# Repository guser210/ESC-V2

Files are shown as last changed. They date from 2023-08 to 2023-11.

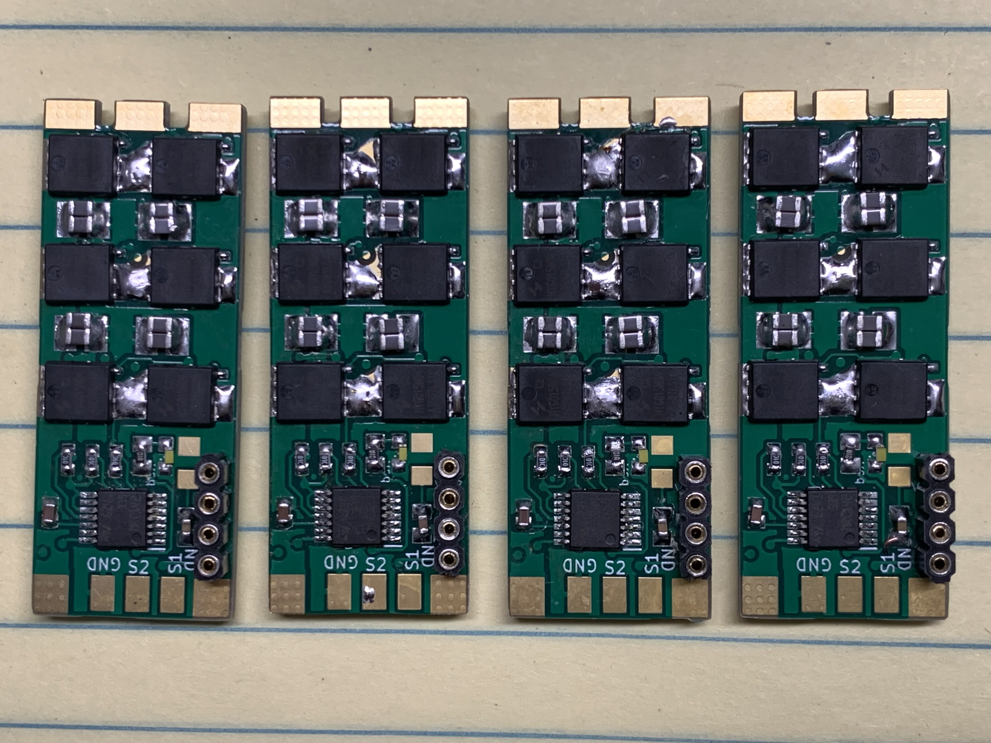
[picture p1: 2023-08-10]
images/ESC back.jpg

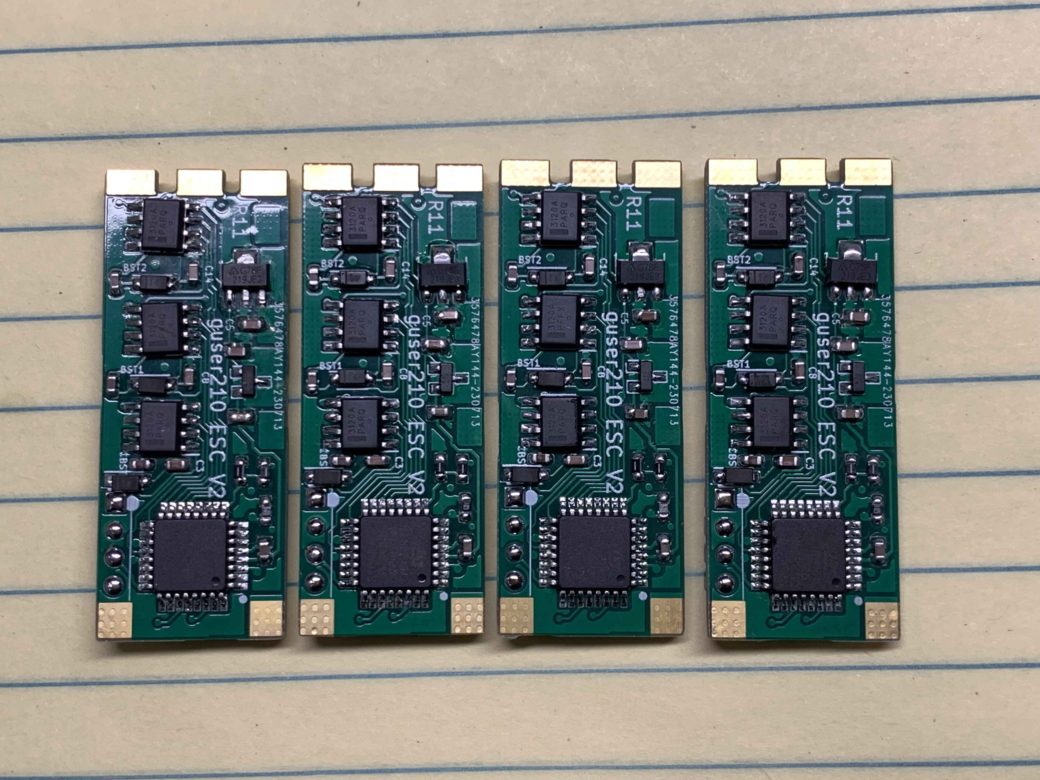
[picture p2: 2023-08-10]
images/ESC Front.jpg

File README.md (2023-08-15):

# ESC-V2
Full STM32CubeEDI project of the ESC I currently use on my Drones.

You can find more information on the link below,

https://discord.gg/pByahDupYP





ESC Front
ESC back






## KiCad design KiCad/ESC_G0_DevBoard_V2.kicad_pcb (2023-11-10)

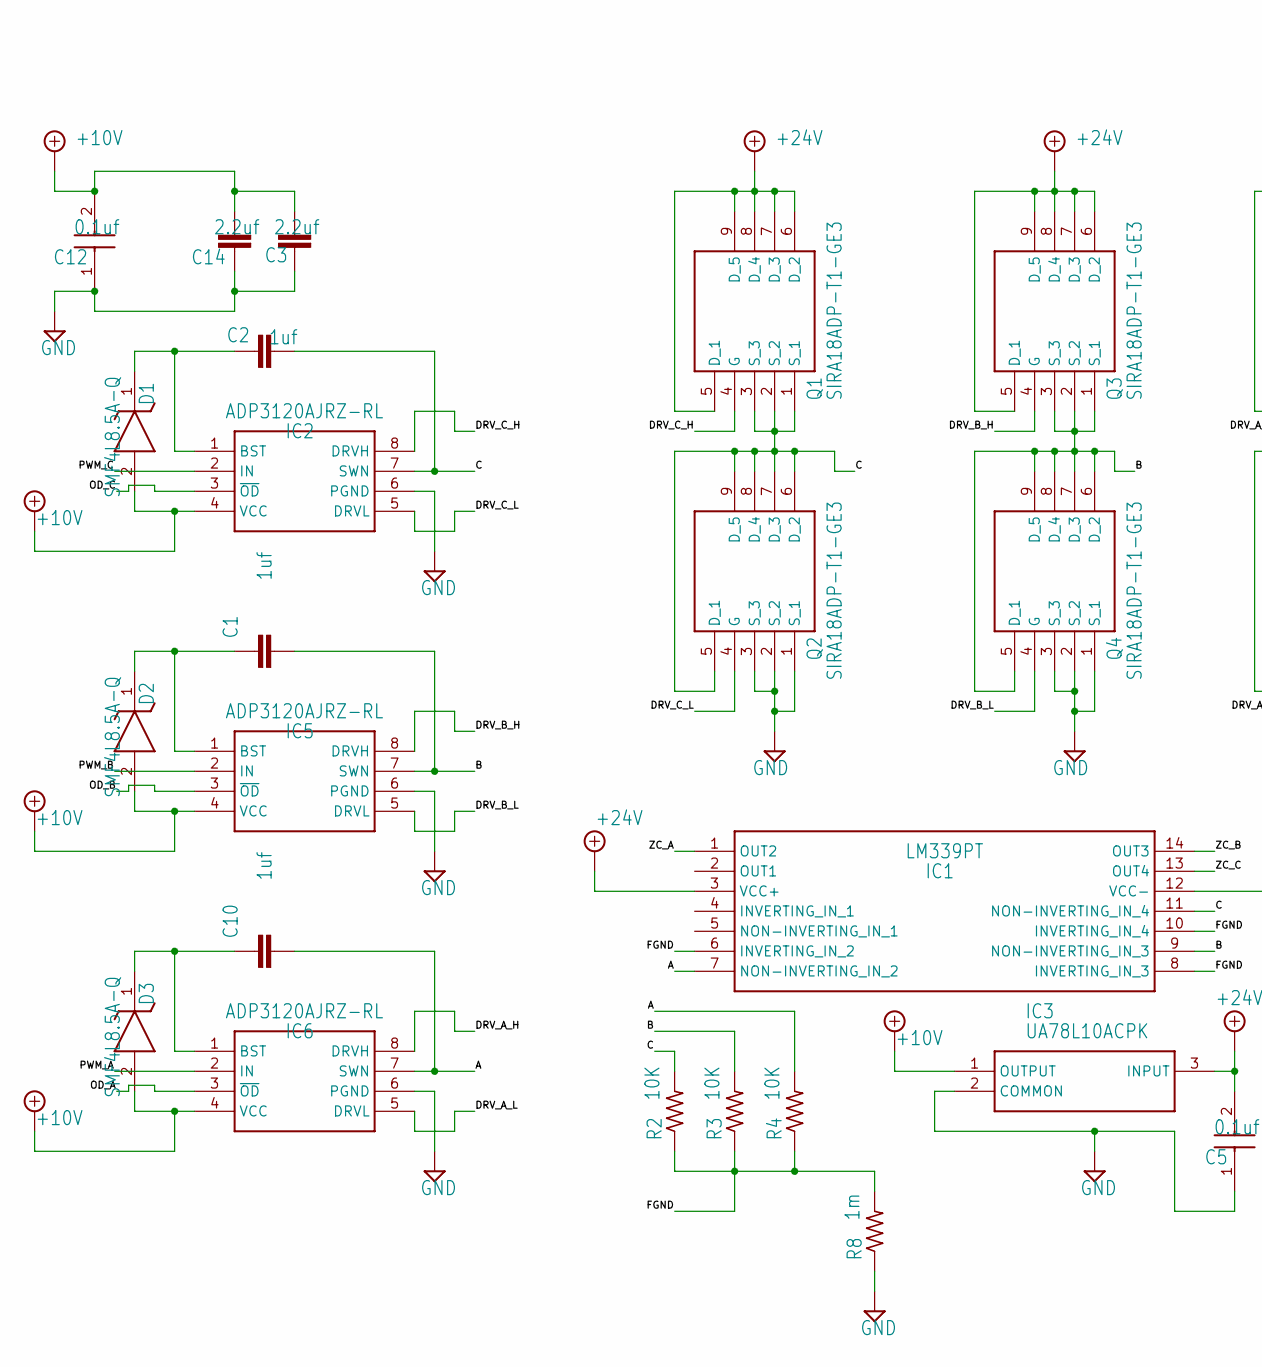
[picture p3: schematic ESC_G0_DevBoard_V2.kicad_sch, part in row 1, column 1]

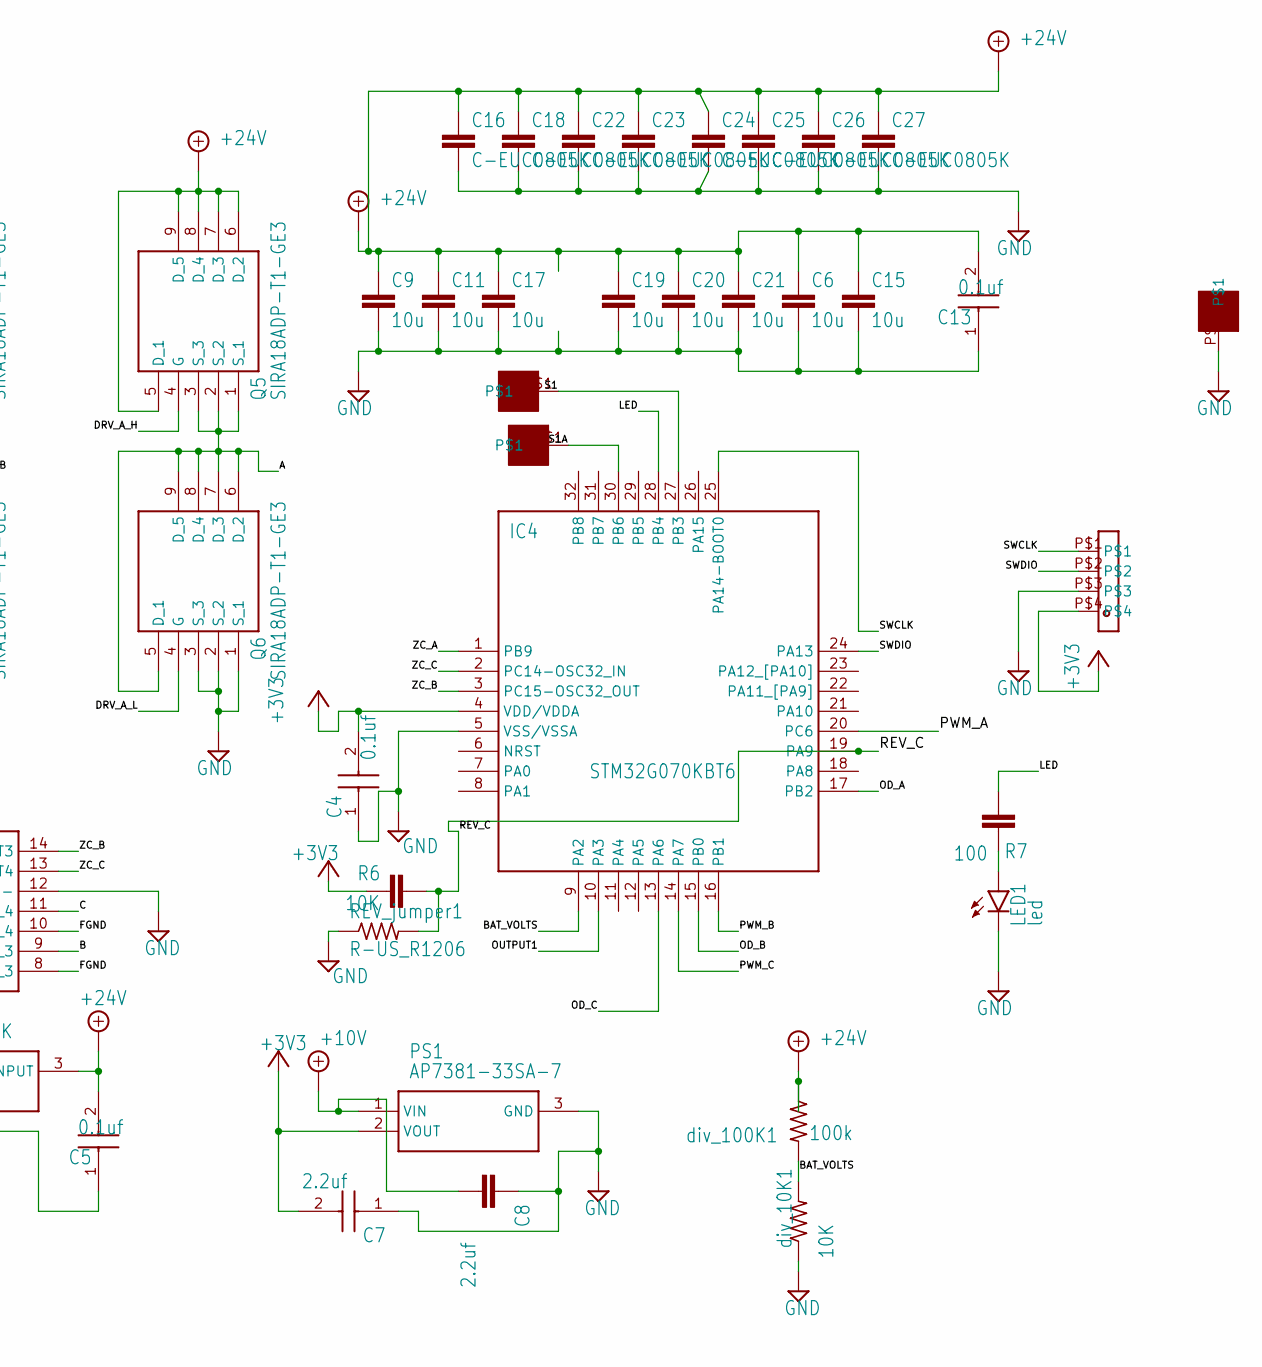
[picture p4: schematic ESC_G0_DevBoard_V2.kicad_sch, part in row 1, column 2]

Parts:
C1, C2, C10: 1uf; C0805K
C3, C8, C14: 2.2uf; C0805K
C4, C5, C12, C13: 0.1uf; CAPC2012X135N
C6, C9, C11, C15, C17, C19, C20, C21: 10u; C1206K
C7: 2.2uf; CAPC2012X135N
C16, C18, C22, C23, C24, C25, C26, C27: C-EUC0805K; C0805K
D1, D2, D3: SMF4L8.5A-Q; SODFL3716X135N
IC1: LM339PT; SOP65P640X120-14N
IC2, IC5, IC6: ADP3120AJRZ-RL; SOIC127P600X175-8N
IC3: UA78L10ACPK; PK(R-PSSO-F3)
IC4: STM32G070KBT6; QFP80P900X900X160-32N
LED1: led; SML0805
PS1: AP7381-33SA-7; SOT96P240X120-3N
Q1, Q2, Q3, Q4, Q5, Q6: SIRA18ADP-T1-GE3; SIRA18ADPT1GE3
R2, R3, R4: 10K; R0603
R6: 10K; C0805K
R7: 100; C0805K
R8: 1m; R0603
REV_jumper1: R-US_R1206; R1206
U$1, U$2, U$3: 3X3_PAD
U$4: STLINK_HEADER
div_10K1: 10K; R0603
div_100K1: 100k; R0603

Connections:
+3V3: C4.2, C7.2, IC4.4 (VDD/VDDA), PS1.2 (VOUT), R6.2, U$4.P$4
+10V: C3.2, C8.2, C12.2, C14.2, D1.2 (A), D2.2 (A), D3.2 (A), IC2.4 (VCC), IC3.1 (OUTPUT), IC5.4 (VCC), IC6.4 (VCC), PS1.1 (VIN)
+24V: C5.2, C6.1, C9.1, C11.1, C13.2, C15.1, C16.1, C17.1, C18.1, C19.1, C20.1, C21.1, C22.1, C23.1, C24.1, C25.1, C26.1, C27.1, IC1.3 (VCC+), IC3.3 (INPUT), Q1.5 (D_1), Q1.6 (D_2), Q1.7 (D_3), Q1.8 (D_4), Q1.9 (D_5), Q3.5 (D_1), Q3.6 (D_2), Q3.7 (D_3), Q3.8 (D_4), Q3.9 (D_5), Q5.5 (D_1), Q5.6 (D_2), Q5.7 (D_3), Q5.8 (D_4), Q5.9 (D_5), div_100K1.1
/A: C10.2, IC1.7 (NON-INVERTING_IN_2), IC6.7 (SWN), Q5.1 (S_1), Q5.2 (S_2), Q5.3 (S_3), Q6.5 (D_1), Q6.6 (D_2), Q6.7 (D_3), Q6.8 (D_4), Q6.9 (D_5), R4.2; also elsewhere on the board
/B: C1.2, IC1.9 (NON-INVERTING_IN_3), IC5.7 (SWN), Q3.1 (S_1), Q3.2 (S_2), Q3.3 (S_3), Q4.5 (D_1), Q4.6 (D_2), Q4.7 (D_3), Q4.8 (D_4), Q4.9 (D_5), R3.2; also elsewhere on the board
/BAT_VOLTS: IC4.9 (PA2), div_10K1.2, div_100K1.2
/C: C2.2, IC1.11 (NON-INVERTING_IN_4), IC2.7 (SWN), Q1.1 (S_1), Q1.2 (S_2), Q1.3 (S_3), Q2.5 (D_1), Q2.6 (D_2), Q2.7 (D_3), Q2.8 (D_4), Q2.9 (D_5), R2.2; also elsewhere on the board
/DRV_A_H: IC6.8 (DRVH), Q5.4 (G)
/DRV_A_L: IC6.5 (DRVL), Q6.4 (G)
/DRV_B_H: IC5.8 (DRVH), Q3.4 (G)
/DRV_B_L: IC5.5 (DRVL), Q4.4 (G)
/DRV_C_H: IC2.8 (DRVH), Q1.4 (G)
/DRV_C_L: IC2.5 (DRVL), Q2.4 (G)
/FGND: IC1.6 (INVERTING_IN_2), IC1.8 (INVERTING_IN_3), IC1.10 (INVERTING_IN_4), R2.1, R3.1, R4.1, R8.2
/LED: IC4.28 (PB4), R7.2
/OD_A: IC4.17 (PB2), IC6.3 (~OD)
/OD_B: IC4.15 (PB0), IC5.3 (~OD)
/OD_C: IC2.3 (~OD), IC4.13 (PA6)
/OUTPUT1: IC4.10 (PA3)
/PWM_A: IC4.20 (PC6), IC6.2 (IN)
/PWM_B: IC4.16 (PB1), IC5.2 (IN)
/PWM_C: IC2.2 (IN), IC4.14 (PA7)
/REV_C: IC4.19 (PA9), R6.1, REV_jumper1.2
/S1: IC4.27 (PB3), U$1.P$1
/S1A: IC4.30 (PB6), U$2.P$1
/SWCLK: IC4.25 (PA14-BOOT0), U$4.P$1
/SWDIO: IC4.24 (PA13), U$4.P$2
/ZC_A: IC1.1 (OUT2), IC4.1 (PB9)
/ZC_B: IC1.14 (OUT3), IC4.3 (PC15-OSC32_OUT)
/ZC_C: IC1.13 (OUT4), IC4.2 (PC14-OSC32_IN)
GND: C3.1, C4.1, C5.1, C6.2, C7.1, C8.1, C9.2, C11.2, C12.1, C13.1, C14.1, C15.2, C16.2, C17.2, C18.2, C19.2, C20.2, C21.2, C22.2, C23.2, C24.2, C25.2, C26.2, C27.2, IC1.12 (VCC-), IC2.6 (PGND), IC3.2 (COMMON), IC3.4, IC4.5 (VSS/VSSA), IC5.6 (PGND), IC6.6 (PGND), LED1.C, PS1.3 (GND), Q2.1 (S_1), Q2.2 (S_2), Q2.3 (S_3), Q4.1 (S_1), Q4.2 (S_2), Q4.3 (S_3), Q6.1 (S_1), Q6.2 (S_2), Q6.3 (S_3), R8.1, REV_jumper1.1, U$3.P$1, U$4.P$3, div_10K1.1
unnamed 31: C1.1, D2.1 (K), IC5.1 (BST); also elsewhere on the board
unnamed 32: C2.1, D1.1 (K), IC2.1 (BST); also elsewhere on the board
unnamed 33: C10.1, D3.1 (K), IC6.1 (BST); also elsewhere on the board
unnamed: LED1.A, R7.1

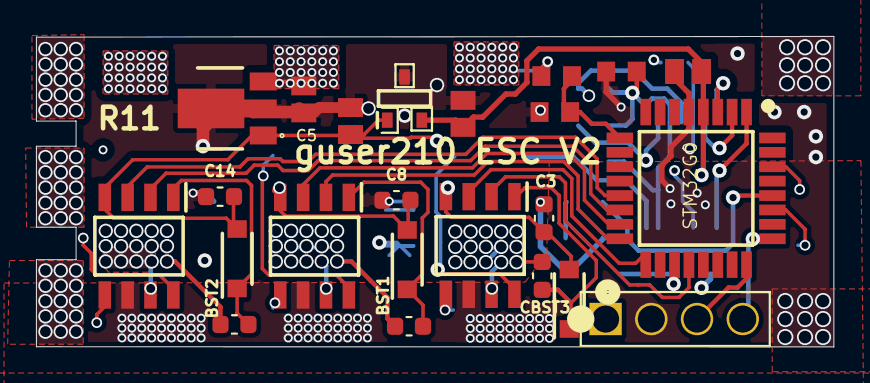
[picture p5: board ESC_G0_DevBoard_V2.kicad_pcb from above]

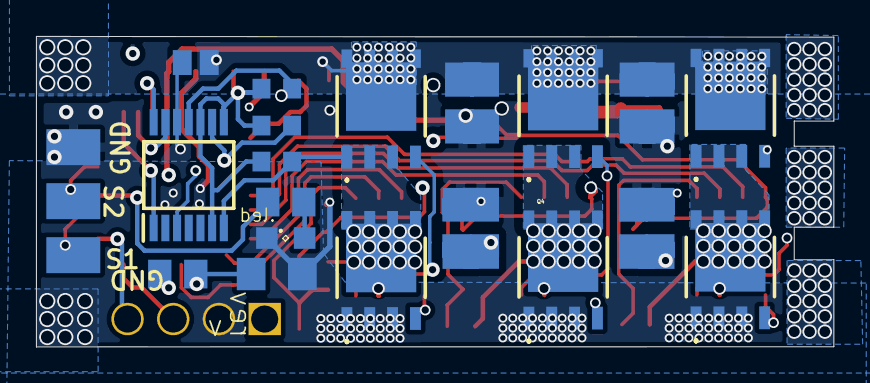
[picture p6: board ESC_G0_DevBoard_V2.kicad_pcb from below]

Board: 8 copper layers, 44.3 x 17.2 mm, 57 parts (34 on the bottom side), 34 nets.

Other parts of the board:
BST1, BST2: 1uf; C_0603_1608Metric
CBST3: 1uf; C_0603_1608Metric

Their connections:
/A: CBST3.2; also elsewhere on the board
/B: BST1.2; also elsewhere on the board
/C: BST2.2; also elsewhere on the board
unnamed 31: BST1.1; also elsewhere on the board
unnamed 32: BST2.1; also elsewhere on the board
unnamed 33: CBST3.1; also elsewhere on the board

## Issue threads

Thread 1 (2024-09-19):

Can do install am32 firmware?

adamalbarr, 2024-09-19:

aviontics, 2025-01-28:
What firmware does it support?

guser210, 2025-02-23:
This is demo project with less than ideal fet drivers, I do not believe there is firmware compatible with it.

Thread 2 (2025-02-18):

Inquiry About Using ESC V2 for Custom PCB

dstromeng, 2025-02-18:
First off, great work on this project! I’ve been going through your ESC V2 design and firmware, and I’d like to use it as the foundation for a custom PCB for my application. I have a few questions regarding your implementation:

1. Have you designed your own MCU breakout board for this project, or are you using an off-the-shelf development board?

2. Can this ESC be controlled using a standard PWM signal or an RC servo signal, or would it require modifications?

I appreciate any guidance you can provide, and I’d love to share updates on my custom implementation as I progress.

Thanks.

guser210, 2025-02-23:
Q: Have you designed your own MCU breakout board for this project, or are you using an off-the-shelf development board?
A: I have a newer sinlge ESC board design compatible with other firmware.

Q: Can this ESC be controlled using a standard PWM signal or an RC servo signal, or would it require modifications?
A: not in this current firmware however, I have new firmware coming out soon for the AT32F4 MCU, Current firmware of Gil32 is closed for now.
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

dstromeng, 2025-02-23:
Hi @guser210
Thanks for getting back.

I have made the custom PCB based on ESC v2 and will be testing it once it arrives sometimes next week.
I am not a PCB designer by far but hopefully it should work.

It would be really interesting to build and test your ESC V3 with Firmware V3.
Let me know if that's possible.

Regards.

guser210, 2025-02-23:
I can give you the design files on my discord, I will be available later tonight (USA time).

https://discord.gg/pByahDupYP

dstromeng, 2025-02-23:
Hi @guser210
I says the discord link is expired

guser210, 2025-02-23:
https://discord.gg/QbzVhgNJhk

dstromeng, 2025-02-23:
Hi @guser210
That works.
Thanks

dstromeng, 2025-02-24:
Hi @guser210
Can the V3 firmware work with v2 ESSc?

Regards.

dstromeng, 2025-02-25:
Hi @guser210
Funny enough I haven't used discord that much before.
Have you already shared V3 firmware and designs.

I did join your server using the link but couldn't find anything.

Regards.

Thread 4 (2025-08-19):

Support Needed for ESC V2

aiswaryaaishh, 2025-08-19:
Dear Sir,

I have assembled and tested the ESC V2 design from your GitHub repository, but it is not working as expected. The MOSFET driver is not switching properly. Could you please suggest a solution to fix this issue?

I am glad to be in touch with you. Thank you.

guser210, 2025-08-24:
Sorry, this project was done as a demo and I am not supporting it, I do have a supported project called Gil32_Firmware and bootloader.

aiswaryaaishh, 2025-08-30:
If the Gill32_Firmware includes any hardware design, could you please share it?

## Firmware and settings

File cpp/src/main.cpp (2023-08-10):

/*
 * main.cpp
 * ESC_V1.4_TEST_Variable
 *  Created on: July 18, 2022
 *      Author: gvargas
 */

#include "main.h"

extern "C" {
extern TIM_HandleTypeDef htim1;		// Signal input capture.
extern TIM_HandleTypeDef htim3;		// PWM driver.
extern TIM_HandleTypeDef htim7;		// Generic timer.

extern TIM_HandleTypeDef htim6;		// RPM.
extern TIM_HandleTypeDef htim14;		// RPM.
extern TIM_HandleTypeDef htim15;		// Low Bat warning.

extern TIM_HandleTypeDef htim16;	// commutator delay.
extern TIM_HandleTypeDef htim17;	// commutator bump timer.
extern ADC_HandleTypeDef hadc1;	// battery voltages.
extern DMA_HandleTypeDef hdma_memtomem_dma1_channel6;
extern DMA_HandleTypeDef hdma_tim1_ch3;


extern volatile uint8_t initComplete;

}

volatile uint8_t disableBump;

volatile uint32_t eRPM = 0;
volatile uint32_t RPM = 0;
volatile uint32_t RPMOld = 0;
volatile uint32_t maxRPM = 0;

volatile uint8_t newDmaSignal = 0;
volatile uint16_t dmaSignal[32] = { 0 };
volatile uint16_t dmaSignalESC[32] = { 0 };
volatile uint16_t dmaSignalMem2Mem[32] = { 0 };
volatile int16_t dmaSignalDiff[33] = { 0 };
volatile uint16_t dmaSignalNormalized[32] = { 0 };
volatile uint16_t dmaESCSignal[33] = { 0 };
volatile uint16_t motorSpeed = 0;
volatile uint16_t motorSpeedCurrent = 0;
volatile uint16_t motorSpeedCurrentOld = 0;
//void beepNoSPin(uint16_t ms ,uint16_t ps );
void beepNoSPin(uint16_t ms = 40, uint16_t ps = 24);
inline uint16_t map(int x, int in_min, int in_max, int out_min, int out_max);
//////////////////////////////////////////////////////////////////////
const uint16_t dmaPulse = 1;
const uint16_t dmaPulseReload = 1024;	//2048;//1024;//512;
//const uint16_t dmaPulse = 2;
//const uint16_t dmaPulseReload = 512;
volatile uint16_t dmaBuffer[dmaPulse] = { 0 };
volatile uint16_t dmaBufferA[dmaPulse] = { 0 };
volatile uint16_t dmaBufferB[dmaPulse] = { 0 };
volatile uint16_t dmaBufferC[dmaPulse] = { 0 };
volatile uint16_t resolution = dmaPulse * dmaPulseReload;

inline void startMotors();
inline void stopMotors();

const uint32_t zcOff[6] = {	//
		ZC_B_Pin, // B
		ZC_A_Pin, // A
		ZC_C_Pin, // C
		ZC_B_Pin, // B
		ZC_A_Pin, // A
		ZC_C_Pin, // C
	};

const uint32_t odLow[6] = { //
		OD_C_Pin, // C
		OD_C_Pin, // C
		OD_A_Pin, // A
		OD_A_Pin, // A
		OD_B_Pin, // B
		OD_B_Pin, // B
	};
const uint32_t odHigh[6] = { //
		OD_A_Pin, // A
		OD_B_Pin, // B
		OD_B_Pin, // B
		OD_C_Pin, // C
		OD_C_Pin, // C
		OD_A_Pin, // A
	};

const uint32_t odOff[6] = { //
		OD_B_Pin, // B
		OD_A_Pin, // A
		OD_C_Pin, // C
		OD_B_Pin, // B
		OD_A_Pin, // A
		OD_C_Pin, // C
	};
//const DMA_HandleTypeDef dmaOff[6] = { (DMA_HandleTypeDef) hdma_tim3_ch3, // B
//		(DMA_HandleTypeDef) hdma_tim3_ch2, // A
//		(DMA_HandleTypeDef) hdma_tim3_ch4, // C
//		(DMA_HandleTypeDef) hdma_tim3_ch3, // B
//		(DMA_HandleTypeDef) hdma_tim3_ch2, // A
//		(DMA_HandleTypeDef) hdma_tim3_ch4, // C
//		};

const uint32_t diOff[6] = { // TIM3->DIER for PWM output RM0454 page .
		1 << 12, // B
		1 <<  9, // A
		1 << 10, // C
		1 << 12, // B
		1 <<  9, // A
		1 << 10, // C
		};
const uint32_t ccOff[6] = { // TIME3->CCER For pwm output, RM0454 page 495.
		1 << 12, // B
		1 <<  0, // A
		1 <<  4, // C
		1 << 12, // B
		1 <<  0, // A
		1 <<  4, // C
		};
const uint32_t ccOn[6] = { // TIME3->CCER For pwm output, RM0454 page 495.
		1 <<  0, // A
		1 << 12, // B
		1 << 12, // B
		1 <<  4, // C
		1 <<  4, // C
		1 <<  0, // A
		};

const uint32_t diOn[6] = { // TIM3->DIER for PWM output RM0454 page .
		1 <<  9, // A
		1 << 12, // B
		1 << 12, // B
		1 << 10, // C
		1 << 10, // C
		1 <<  9, // A
		};
GPIO_TypeDef *odrOff[6] = { //
		(GPIO_TypeDef*) OD_B_GPIO_Port, // B
		(GPIO_TypeDef*) OD_A_GPIO_Port, // A
		(GPIO_TypeDef*) OD_C_GPIO_Port, // C
		(GPIO_TypeDef*) OD_B_GPIO_Port, // B
		(GPIO_TypeDef*) OD_A_GPIO_Port, // A
		(GPIO_TypeDef*) OD_C_GPIO_Port, // C
	};
GPIO_TypeDef *odrLow[6] = { //
		(GPIO_TypeDef*) OD_C_GPIO_Port, // C
		(GPIO_TypeDef*) OD_C_GPIO_Port, // C
		(GPIO_TypeDef*) OD_A_GPIO_Port, // A
		(GPIO_TypeDef*) OD_A_GPIO_Port, // A
		(GPIO_TypeDef*) OD_B_GPIO_Port, // B
		(GPIO_TypeDef*) OD_B_GPIO_Port, // B
	};
GPIO_TypeDef *odrHigh[6] = { //
		(GPIO_TypeDef*) OD_A_GPIO_Port, // A
		(GPIO_TypeDef*) OD_B_GPIO_Port, // B
		(GPIO_TypeDef*) OD_B_GPIO_Port, // B
		(GPIO_TypeDef*) OD_C_GPIO_Port, // C
		(GPIO_TypeDef*) OD_C_GPIO_Port, // C
		(GPIO_TypeDef*) OD_A_GPIO_Port, // A
	};
__IO uint32_t *ccrHigh[6] = { //
		&TIM3->CCR1, // A
		&TIM3->CCR4, // B
		&TIM3->CCR4, // B
		&TIM3->CCR2, // C
		&TIM3->CCR2, // C
		&TIM3->CCR1, // A
};
__IO uint32_t *ccrOff[6] = { //
		&TIM3->CCR4, // B
		&TIM3->CCR1, // A
		&TIM3->CCR2, // C
		&TIM3->CCR4, // B
		&TIM3->CCR1, // A
		&TIM3->CCR2, // C
};
__IO uint32_t *ccrLow[6] = { //
		&TIM3->CCR2, // C
		&TIM3->CCR2, // C
		&TIM3->CCR1, // A
		&TIM3->CCR1, // A
		&TIM3->CCR4, // B
		&TIM3->CCR4, // B
};

const GPIO_TypeDef *zcPortOff[6] = { //
		(GPIO_TypeDef*) ZC_B_GPIO_Port, // B
				(GPIO_TypeDef*) ZC_A_GPIO_Port, // A
				(GPIO_TypeDef*) ZC_C_GPIO_Port, // C
				(GPIO_TypeDef*) ZC_B_GPIO_Port, // B
				(GPIO_TypeDef*) ZC_A_GPIO_Port, // A
				(GPIO_TypeDef*) ZC_C_GPIO_Port, // C
		};

volatile uint32_t resetImrFlags = 0;
volatile uint8_t powerStep = 0;
volatile uint8_t powerStepCurrent = 0;
volatile uint8_t powerStepNext = 0;

const uint8_t rising[2][6] = { { 1, 0, 1, 0, 1, 0 }, { 0, 1, 0, 1, 0, 1 } };

volatile uint8_t reverse = 0;

#define zcPinOn ZC_A_Pin | ZC_B_Pin | ZC_C_Pin
volatile uint16_t commutationCNT = 0;
volatile uint16_t commutationCNT14 = 0;
volatile uint16_t commutationCntPrev = 0;
volatile uint16_t commutation6Step = 0;
volatile uint8_t motorSpinning = 0;


void setDutyCycle(uint16_t dc) {
	//return;
	if (dc > resolution)
		dc = resolution;

	if (dc > resolution)
		dc = resolution;

	dmaBuffer[0] = dc;

	__disable_irq();
	*ccrHigh[powerStep] = dc;
	__enable_irq();


}


volatile uint32_t fallingCount = 0;
volatile uint32_t risingCount = 0;
volatile uint32_t commutatingCount = 0;

inline void commutate() {
	// go to next power step.
	commutatingCount++;
	powerStep = powerStepNext;

	static uint16_t odr = 0;

	/*
	 Step 0  1   2  3  4  5      0  1  2  3  4  5
	 High A  B   B  C  C  A      A  B  B  C  C  A
	 Off  B  A   C  B  A  C      B  A  C  B  A  C
	 Low  C  C   A  A  B  B      C  C  A  A  B  B
	 */
//		reverse = 0;

	odrOff[powerStep]->BRR = odOff[powerStep];
	*ccrHigh[powerStep] = dmaBuffer[0];
	*ccrOff[powerStep] = 0;
	odrLow[powerStep]->BSRR = odLow[powerStep];
	odrHigh[powerStep]->BSRR = odHigh[powerStep];

	if (rising[reverse][powerStep]) {

		EXTI->FTSR1 = 0;
		EXTI->RTSR1 = zcOff[powerStep];

	} else {
		EXTI->RTSR1 = 0;
		EXTI->FTSR1 = zcOff[powerStep];

	}

	TIM16->CNT = 0;
	powerStepCurrent++;
	powerStepCurrent %= 6;

//	if( motorSpeedCurrent == 0)
//		motorSpinning = 0;
	if ( initComplete == 0) //|| motorSpeedCurrent == 0)
	{
		HAL_NVIC_DisableIRQ(EXTI4_15_IRQn);
	}

	if (reverse)
		powerStepNext = 5 - powerStepCurrent;
	else
		powerStepNext = powerStepCurrent; // forward.

	if (powerStepNext == 0) {
		commutationCNT = TIM6->CNT;
		TIM6->CNT = 0;
	} else if (powerStepNext == 3) {
		commutationCNT14 = TIM14->CNT;
		TIM14->CNT = 0;
	}

	// enable wakeup with interrupt.
	EXTI->IMR1 = resetImrFlags | zcOff[powerStep];
	// clear any zc pending interrupts.
	EXTI->FPR1 = zcPinOn;
	;
	EXTI->RPR1 = zcPinOn;
	;
	// reset timer17 for bump motor.
	TIM17->CNT = 0;

}

volatile uint32_t newARR = 2047; //3076;
volatile uint16_t checkRising = 0;
volatile uint16_t checkFalling = 0;


void HAL_GPIO_EXTI_Rising_Callback(uint16_t GPIO_Pin) {

	if( TIM16->CNT > 300)
	{
		TIM16->CNT = 0;
		EXTI->IMR1 = resetImrFlags ;
		risingCount++;
		motorSpeedCurrent >>=1;
		return;
	}
	TIM7->CNT = 0;
	while ( TIM7->CNT < checkRising)
		if ((zcPortOff[powerStep]->IDR & zcOff[powerStep]) == 0)
			return;


	commutate();
}
void HAL_GPIO_EXTI_Falling_Callback(uint16_t GPIO_Pin) {


	if( TIM16->CNT > 300)
	{
		TIM16->CNT = 0;
		EXTI->IMR1 = resetImrFlags ;
		fallingCount++;
		motorSpeedCurrent >>=1;
		return;
	}

	TIM7->CNT = 0;
	while ( TIM7->CNT < checkFalling)
		if ((zcPortOff[powerStep]->IDR & zcOff[powerStep]))
			return;

	commutate();
}

volatile uint8_t lowBattery = 0;

//////////////////////////////////////////////////////////////////////

uint16_t divClosest(uint16_t a, uint16_t b) {
	return (a + b / 2) / b;
}

volatile uint16_t pwm[3] = { 0 };

volatile uint16_t pwmRising[5] = { 0 };
volatile uint16_t pwmFalling[5] = { 0 };
volatile uint8_t pwmAvgCounter = 0;

volatile uint8_t transmitterDirection = 0;
volatile uint8_t masterDirection = 0;
volatile uint16_t pwm1 = 0;
volatile uint16_t pwm2 = 0;

volatile uint8_t directionValidator = 0;

volatile uint32_t numberOfTimesDshotProcessed = 0; // Debug Variable
volatile uint32_t numberOfTimesDshotMiddleOfFrame = 0; // Debug variable.
volatile uint32_t numberOfTimesDshotCRCError = 0; // Debug Variable
volatile uint32_t numberOfTimesDshotThrottleOver = 0; // Debug Variable
volatile uint32_t numberOfTimesDshotTimeAdvace = 0; // Debug Variable
volatile uint32_t numberOfTimesDshotResync = 0; // Debug Variable

volatile uint16_t debugCounter = 0;

volatile uint16_t dmaSignalNormalized2[16] = { 0 };
static volatile uint8_t errorReads = 0;

static volatile uint16_t throttle = 0;
static volatile uint16_t dshotCommand = 0;
static volatile int16_t throttlePlusTel = 0;
static volatile uint16_t crcIn = 0;
static volatile uint16_t crc = 0;
static volatile uint16_t telemetryBit = 0;
static volatile uint16_t signal[16] = { 0 };

volatile uint16_t bumps = 0;
void HAL_TIM_PeriodElapsedCallback(TIM_HandleTypeDef *htim) {
	if (htim == &htim15) //&& htim->Channel == HAL_TIM_ACTIVE_CHANNEL_1)
			{
		if (lowBattery || motorSpeedCurrent > 0) {
			LED_GPIO_Port->BRR = LED_Pin;
		}
	} else if (htim == &htim17) {

	}

}

void HAL_TIM_OC_DelayElapsedCallback(TIM_HandleTypeDef *htim) { // guser210

	if (htim == &htim1 && htim->Channel == HAL_TIM_ACTIVE_CHANNEL_1) {
		TIM1->DIER &= ~((1 << 1) | (1 << 4)); // Disable interrupts for channel 1 and 4.

		// Enable Signal DMA.
		TIM1->CNT = 0;
		hdma_tim1_ch3.Instance->CNDTR = 32; // First set number of bytes to transfer
		hdma_tim1_ch3.Instance->CCR |= 1; // second enable DMA channel.

		numberOfTimesDshotResync++;

	} else if (htim == &htim17 && htim->Channel == HAL_TIM_ACTIVE_CHANNEL_1) {

		TIM17->CNT = 0;
		if (initComplete > 0 && motorSpeedCurrent > 0) { // Bump
			LED_GPIO_Port->ODR ^= LED_Pin;
			bumps++;
			commutate();
		} else if (motorSpeedCurrent == 0)

		{

		}
	} else if (htim == &htim15 && htim->Channel == HAL_TIM_ACTIVE_CHANNEL_1) {
		if (lowBattery) {
			LED_GPIO_Port->BSRR = LED_Pin;
		}
	}

}
void HAL_TIM_IC_CaptureCallback(TIM_HandleTypeDef *htim) {

	if (htim == &htim1) {
		if (htim->Channel == HAL_TIM_ACTIVE_CHANNEL_3) {
			if (newDmaSignal == 0) {
				//MEM2MEM launch.
				hdma_memtomem_dma1_channel6.Instance->CNDTR = 32;
				hdma_memtomem_dma1_channel6.Instance->CCR |= 1;
				newDmaSignal = 1;
			}

			// reset CNT  to prevent early overflow.
			TIM1->CNT = 0;
		} else if (htim->Channel == HAL_TIM_ACTIVE_CHANNEL_4) {
			TIM1->CCR1 = TIM1->CNT + 120; // advance OC of channel 1 if rising edge.

			// increment debug counter.
			numberOfTimesDshotTimeAdvace++;
		}
	}
}
volatile int motorSpeedDirection = 1;
volatile uint32_t beepCounter = 0;
volatile uint8_t direction = 0;
volatile uint8_t DShotCommandCount = 0;
volatile uint8_t DShotCommandList[128] = { 0 };

// TODO:Step 3

inline void processDmaSignalDShot() {

	/* Gap 0 = 1.07, 1 = 504
	 * Protocol Type 		Dshot 150 	Dshot 300	Dshot 600	Dshot 1200
	 * Period time			6.67 µs 	3.33 µs 	1.67 µs 	0.833 µs
	 * Zero high time (T0H) 2.50 µs 	1.25 µs 	0.625 µs 	0.313 µs
	 * One high time (T1H) 	5.00 µs 	2.50 µs 	1.25 µs 	0.625 µs
	 * https://brushlesswhoop.com/dshot-and-bidirectional-dshot/
	 */

	numberOfTimesDshotProcessed++;

	/*
	 * wait for mem2mem to complete, this is unlikley to happen since it takes time
	 * to get to this funciton. is a safety check.
	 */

	while (hdma_memtomem_dma1_channel6.Instance->CNDTR > 0)
		;
	// Disble mem2mem channel... this is required for re-activation.
	hdma_memtomem_dma1_channel6.Instance->CCR &= ~(1);

	//check if middle of frame.
	if (dmaSignalESC[0] > dmaSignalESC[31]) // || dmaSignalESC[15] > dmaSignalESC[31])
			{
		TIM1->CNT = 0; // reset counter to 0 to prevent overflows.
		TIM1->CCR1 = 50;
		hdma_tim1_ch3.Instance->CCR &= ~(1); // Disable Signal DMA
		TIM1->DIER |= (1 << 1) | (1 << 4); // enable interrupts for Channels 1 and 4.

		numberOfTimesDshotMiddleOfFrame++;
		newDmaSignal = 0;
		return; // invalid data exit function.
	}

	static uint8_t ShiftBy = 5;

	signal[0] = (dmaSignalESC[1] - dmaSignalESC[0]) >> ShiftBy;
	signal[1] = (dmaSignalESC[3] - dmaSignalESC[2]) >> ShiftBy;
	signal[2] = (dmaSignalESC[5] - dmaSignalESC[4]) >> ShiftBy;
	signal[3] = (dmaSignalESC[7] - dmaSignalESC[6]) >> ShiftBy;
	signal[4] = (dmaSignalESC[9] - dmaSignalESC[8]) >> ShiftBy;
	signal[5] = (dmaSignalESC[11] - dmaSignalESC[10]) >> ShiftBy;
	signal[6] = (dmaSignalESC[13] - dmaSignalESC[12]) >> ShiftBy;
	signal[7] = (dmaSignalESC[15] - dmaSignalESC[14]) >> ShiftBy;
	signal[8] = (dmaSignalESC[17] - dmaSignalESC[16]) >> ShiftBy;
	signal[9] = (dmaSignalESC[19] - dmaSignalESC[18]) >> ShiftBy;
	signal[10] = (dmaSignalESC[21] - dmaSignalESC[20]) >> ShiftBy;
	signal[11] = (dmaSignalESC[23] - dmaSignalESC[22]) >> ShiftBy;
	signal[12] = (dmaSignalESC[25] - dmaSignalESC[24]) >> ShiftBy;
	signal[13] = (dmaSignalESC[27] - dmaSignalESC[26]) >> ShiftBy;
	signal[14] = (dmaSignalESC[29] - dmaSignalESC[28]) >> ShiftBy;
	signal[15] = (dmaSignalESC[31] - dmaSignalESC[30]) >> ShiftBy;

	newDmaSignal = 0;

	throttlePlusTel = (signal[0]) << 11 | (signal[1]) << 10 | (signal[2]) << 9
			| (signal[3]) << 8 | (signal[4]) << 7 | (signal[5]) << 6
			| (signal[6]) << 5 | (signal[7]) << 4 | (signal[8]) << 3
			| (signal[9]) << 2 | (signal[10]) << 1 | (signal[11]);

	throttle = throttlePlusTel >> 2; // 1 = 2048, 2 = 1024;
	dshotCommand = throttlePlusTel >> 1;

	crcIn = signal[12] << 3 | signal[13] << 2 | signal[14] << 1 | signal[15];

	// Calculate CRC from 12 MSB.
	crc = (throttlePlusTel ^ (throttlePlusTel >> 4) ^ (throttlePlusTel >> 8))
			& 0x0F;

	if (crc != crcIn || throttle > 1024) {
		if (crc != crcIn)
			numberOfTimesDshotCRCError++; // Increment debug counter.
		if (throttle > 1024)
//		if (throttle > 2048)
			numberOfTimesDshotThrottleOver++; // increment debug counter.
		if (errorReads++ > 10) {

			if (motorSpeed > 1)
				motorSpeed--;
			errorReads = 0;
		}

		TIM1->CNT = 0; // reset counter to 0 to prevent overflows.
		TIM1->CCR1 = 120;
		hdma_tim1_ch3.Instance->CCR &= ~(1); // Disable Signal DMA
		TIM1->DIER |= (1 << 1) | (1 << 4); // enable interrupts for Channels 1 and 4.

		newDmaSignal = 0;
		return; // invalid data exit function.
	}

	telemetryBit = signal[11];

	if (dshotCommand > 0 && dshotCommand < 48 && motorSpeed == 0) {
		DShotCommandList[DShotCommandCount++] = dshotCommand;
		DShotCommandCount %= 128;

		switch (dshotCommand) {
		case 21: // Motor direction: Reverse
			if (masterDirection == direction) {
				//if( directionCounter++ > 3)
				{
//					directionCounter = 0;
					if (direction == 1)
						direction = 0;
					else
						direction = 1;
				}
			}

			break;
		case 20: // Motor direction: Normal
			direction = masterDirection;
			break;
		case 1:
		case 2: // beep 1 and 2
		case 3:
		case 4: // beep 3 and 4
		case 5: // beep 5
			break;
		default:
			break;
		}
		return;

	}

	errorReads = 0;
	newDmaSignal = 0;
	motorSpeed = throttle > 0 ? throttle  : 0; // throttle;


}

void processDmaSignal() {
	newDmaSignal = 0;

	for (int index = 0; index < 15; index++)
		dmaSignalNormalized[index] = divClosest(
				dmaSignal[index + 1] - dmaSignal[index], 8) - 8;

//
	if (dmaSignalNormalized[0] > 1000 && dmaSignalNormalized[1] > 1000
			&& dmaSignalNormalized[2] > 1000) {
		return;
	}

	for (int index = 0; index <= 10; index++) {
		if (dmaSignalNormalized[index] < 100)
			continue;
		if (dmaSignalNormalized[index + 1] > 3000)
			continue;

		uint16_t motorSpeedNewValue = dmaSignalNormalized[index + 1] << 6
				| dmaSignalNormalized[index + 3] << 2
				| dmaSignalNormalized[index + 5] >> 2;
		if (motorSpeedNewValue < 1026)
			motorSpeed = motorSpeedNewValue;

		break;
	}

}

inline uint16_t map(int x, int in_min, int in_max, int out_min, int out_max) {
	if (x < in_min)
		x = in_min;

	if (x > in_max)
		x = in_max;

	return (x - in_min) * (out_max - out_min) / (in_max - in_min) + out_min;
}

const double batteryCellLow = 3.5;
const double batteryCellHigh = 4.29;
const double BatteryLow[7] = { 0, batteryCellLow * 1, batteryCellLow * 2,
		batteryCellLow * 3, batteryCellLow * 4, batteryCellLow * 5,
		batteryCellLow * 6 };

const double BatteryHigh[7] = { 0, batteryCellHigh * 1, batteryCellHigh * 2,
		batteryCellHigh * 3, batteryCellHigh * 4, batteryCellHigh * 5,
		batteryCellHigh * 6 };

volatile double batteryVoltages = 0.0f;
volatile double adcValue = 0;
volatile uint16_t adcValues[4] = { 0 };
volatile uint16_t fallingPaddingValue = 0;
volatile double tempC = 0;
volatile double tempF = 0;
volatile const uint8_t maxTempF = 190;

volatile uint8_t memorySettings[32] = { 0 };
volatile int sizeOfSettings = sizeof(memorySettings);
void readMemory(volatile unsigned char *data, int size, int location) {
	location *= 8;

	for (int index = 0; index < size; index++) {
		data[index] = (unsigned int) (*(uint64_t*) (0x0801F800 + location));
		location += 8;
	}

}

void writeMemory(volatile unsigned char *data, int size, int location) {
	uint8_t memorySettings[32] = { 0 };
	readMemory(memorySettings, sizeOfSettings, 0);

	size = size > sizeOfSettings ? sizeOfSettings : size;
	location = location >= sizeOfSettings ? sizeOfSettings : location;

	for (int index = 0; index < size; index++) {
		location = location >= sizeOfSettings ? sizeOfSettings : location;
		memorySettings[location++] = data[index];
	}

	FLASH_EraseInitTypeDef epage;
	epage.TypeErase = FLASH_TYPEERASE_PAGES; // FLASH_TYPEERASE_PAGES
	epage.Page = 63;
	epage.NbPages = 1;

	uint32_t error = 0;
//	HAL_StatusTypeDef ret =
	HAL_FLASH_Unlock();

//	ret =
	HAL_FLASHEx_Erase(&epage, &error);
	for (int index = 0; index < sizeOfSettings; index++) {
		//ret =
		HAL_FLASH_Program(FLASH_TYPEPROGRAM_DOUBLEWORD,
				0x0801F800 + (index * 8), memorySettings[index]);
	}

	//ret =
	HAL_FLASH_Unlock();

}

void beepNoSPin(uint16_t ms, uint16_t ps) {
	uint32_t psc = TIM3->PSC;

	TIM3->PSC = ps;
	LED_GPIO_Port->BSRR = LED_Pin;
	setDutyCycle(10);
	HAL_Delay(ms);
	LED_GPIO_Port->BRR = LED_Pin;
	setDutyCycle(0);
	commutate();

	TIM3->PSC = psc;
	commutate();

}
void HAL_ADC_ConvCpltCallback(ADC_HandleTypeDef *hadc) {
	adcValue = adcValues[0];
}
void HAL_ADC_ConvHalfCpltCallback(ADC_HandleTypeDef *hadc) {
	adcValue = adcValues[0];
}

volatile uint32_t timTest = 0;
volatile uint32_t timTest2 = 0;
volatile uint8_t throttleChange = 0;

void setup() {

	OD_A_GPIO_Port->BRR = OD_A_Pin;
	OD_B_GPIO_Port->BRR = OD_B_Pin;
	OD_C_GPIO_Port->BRR = OD_C_Pin;
	EXTI->FTSR1 = 0;
	EXTI->RTSR1 = 0;

	resetImrFlags = EXTI->IMR1;
	resetImrFlags &= ~(ZC_A_Pin | ZC_B_Pin | ZC_C_Pin);
	EXTI->IMR1 = resetImrFlags;


	if (HAL_TIM_Base_Start(&htim3) != HAL_OK)
		Error_Handler();

	TIM3->CCR1 = 0;
	TIM3->CCR2 = 0;
//	TIM3->CCR3 = 0;
	TIM3->CCR4 = 0;

	HAL_TIM_PWM_Start(&htim3, TIM_CHANNEL_1);
	HAL_TIM_PWM_Start(&htim3, TIM_CHANNEL_2);
	HAL_TIM_PWM_Start(&htim3, TIM_CHANNEL_4);

	__HAL_TIM_SET_COMPARE(&htim17, TIM_CHANNEL_1, 20);
	HAL_TIM_OC_Start_IT(&htim17, TIM_CHANNEL_1);


	HAL_TIM_Base_Start_IT(&htim15);
	__HAL_TIM_SET_COMPARE(&htim15, TIM_CHANNEL_1, 450);
	HAL_TIM_OC_Start_IT(&htim15, TIM_CHANNEL_1);
	TIM15->CNT = 0;
}
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

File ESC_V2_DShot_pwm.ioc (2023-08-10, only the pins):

Mcu.UserName=STM32G070KBTx
PA13.Signal=SYS_SWDIO
PA14-BOOT0.Signal=SYS_SWCLK
PA2.GPIO_Label=BAT_VOLTS
PA2.Signal=ADC1_IN2
PA6.GPIO_Label=OD_C
PA6.Signal=GPIO_Output
PA7.GPIO_Label=PWM_C
PA7.Signal=S_TIM3_CH2
PA9.GPIO_Label=REV
PA9.Signal=GPIO_Input
PB0.GPIO_Label=OD_B
PB0.Signal=GPIO_Output
PB1.GPIO_Label=PWM_B
PB1.Signal=S_TIM3_CH4
PB2.GPIO_Label=OD_A
PB2.Signal=GPIO_Output
PB3.GPIO_Label=signal
PB3.Signal=GPIO_Output
PB4.GPIO_Label=LED
PB4.Signal=GPIO_Output
PB6.GPIO_Label=Proshot
PB6.Signal=S_TIM1_CH3
PB9.GPIO_Label=ZC_A
PB9.Signal=GPXTI9
PC6.GPIO_Label=PWM_A
PC6.Signal=S_TIM3_CH1

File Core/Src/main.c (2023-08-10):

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
/* Includes ------------------------------------------------------------------*/
#include "main.h"

ADC_HandleTypeDef hadc1;
DMA_HandleTypeDef hdma_adc1;

TIM_HandleTypeDef htim1;
TIM_HandleTypeDef htim3;
TIM_HandleTypeDef htim6;
TIM_HandleTypeDef htim7;
TIM_HandleTypeDef htim14;
TIM_HandleTypeDef htim15;
TIM_HandleTypeDef htim16;
TIM_HandleTypeDef htim17;
DMA_HandleTypeDef hdma_tim1_ch3;

DMA_HandleTypeDef hdma_memtomem_dma1_channel6;
/* USER CODE BEGIN PV */
volatile uint8_t initComplete = 0;
/* USER CODE END PV */

void SystemClock_Config(void);
static void MX_GPIO_Init(void);
static void MX_DMA_Init(void);
static void MX_TIM1_Init(void);
static void MX_TIM3_Init(void);
static void MX_ADC1_Init(void);
static void MX_TIM7_Init(void);
static void MX_TIM17_Init(void);
static void MX_TIM6_Init(void);
static void MX_TIM14_Init(void);
static void MX_TIM16_Init(void);
static void MX_TIM15_Init(void);
/**
  * @brief  The application entry point.
  * @retval int
  */
int main(void)
{
  /* MCU Configuration--------------------------------------------------------*/

  /* Reset of all peripherals, Initializes the Flash interface and the Systick. */
  HAL_Init();

  /* Configure the system clock */
  SystemClock_Config();

  /* USER CODE BEGIN SysInit */
//  MX_GPIO_Init();
//  HAL_NVIC_DisableIRQ(EXTI4_15_IRQn);
//  MX_DMA_Init();
//  MX_TIM1_Init();
//  MX_TIM3_Init();
//  MX_ADC1_Init();
//  MX_TIM7_Init();
//  MX_TIM17_Init();
//  MX_TIM6_Init();
////  MX_TIM16_Init();
//  MX_TIM14_Init();
//#ifdef _OVERWRITE_
  /* USER CODE END SysInit */

  /* Initialize all configured peripherals */
  MX_GPIO_Init();
  MX_DMA_Init();
  MX_TIM1_Init();
  MX_TIM3_Init();
  MX_ADC1_Init();
  MX_TIM7_Init();
  MX_TIM17_Init();
  MX_TIM6_Init();
  MX_TIM14_Init();
  MX_TIM16_Init();
  MX_TIM15_Init();
  /* USER CODE BEGIN 2 */
//#endif
  /* USER CODE END 2 */

  /* Infinite loop */
  /* USER CODE BEGIN WHILE */


  maincpp();
  while (1)
  {
	  HAL_GPIO_TogglePin(LED_GPIO_Port, LED_Pin);
	  HAL_Delay(100);

    /* USER CODE END WHILE */

    /* USER CODE BEGIN 3 */
  }
  /* USER CODE END 3 */
}

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


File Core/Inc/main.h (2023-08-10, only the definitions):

#define ZC_A_Pin GPIO_PIN_9
#define ZC_A_GPIO_Port GPIOB
#define ZC_A_EXTI_IRQn EXTI4_15_IRQn
#define ZC_C_Pin GPIO_PIN_14
#define ZC_C_GPIO_Port GPIOC
#define ZC_C_EXTI_IRQn EXTI4_15_IRQn
#define ZC_B_Pin GPIO_PIN_15
#define ZC_B_GPIO_Port GPIOC
#define ZC_B_EXTI_IRQn EXTI4_15_IRQn
#define BAT_VOLTS_Pin GPIO_PIN_2
#define BAT_VOLTS_GPIO_Port GPIOA
#define OD_C_Pin GPIO_PIN_6
#define OD_C_GPIO_Port GPIOA
#define PWM_C_Pin GPIO_PIN_7
#define PWM_C_GPIO_Port GPIOA
#define OD_B_Pin GPIO_PIN_0
#define OD_B_GPIO_Port GPIOB
#define PWM_B_Pin GPIO_PIN_1
#define PWM_B_GPIO_Port GPIOB
#define OD_A_Pin GPIO_PIN_2
#define OD_A_GPIO_Port GPIOB
#define REV_Pin GPIO_PIN_9
#define REV_GPIO_Port GPIOA
#define PWM_A_Pin GPIO_PIN_6
#define PWM_A_GPIO_Port GPIOC
#define signal_Pin GPIO_PIN_3
#define signal_GPIO_Port GPIOB
#define LED_Pin GPIO_PIN_4
#define LED_GPIO_Port GPIOB
#define Proshot_Pin GPIO_PIN_6
#define Proshot_GPIO_Port GPIOB

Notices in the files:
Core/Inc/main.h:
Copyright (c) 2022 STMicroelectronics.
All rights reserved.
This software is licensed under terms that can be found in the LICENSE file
